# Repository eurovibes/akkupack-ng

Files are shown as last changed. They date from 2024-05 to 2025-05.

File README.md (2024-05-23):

<!-- SPDX-FileCopyrightText: 2024 Benedikt Spranger <b.spranger@linutronix.de> -->
<!-- SPDX-License-Identifier: CERN-OHL-S-2.0 -->


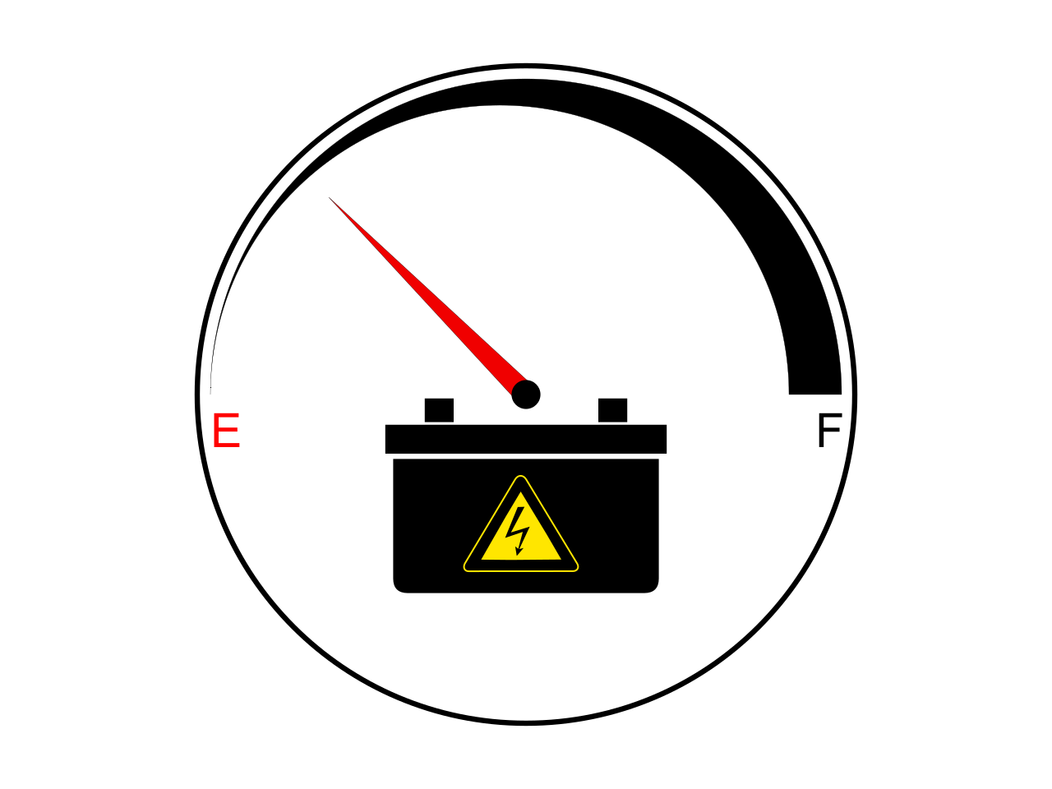
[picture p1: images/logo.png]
Akkupack-Ng logo


# Akkupack-NG - A AKKU-Pack gas gauge

## License rules

akkupack-ng is provided under the terms of the CERN-OHL-S license
version 2 as provided in the LICENSES/CERN-OHL-S-2.0 file.

Instead of adding license boilerplates to the individual files,
akkupack-ng uses SPDX license identifiers, which are machine parseable
and considered legaly equivalent.

The SPDX license identifier in akkupack-ng shall be added at the first
possible line in a file which can contain a comment. This is normally the
first line except for scripts. Scripts require the #!PATH_TO_INTERPRETER tag
in the first line; place the SPDX identifier into the second line.

The SPDX license identifier is added in form of a comment.

## Copyright and License

> Copyright Benedikt Spranger 2024.
> This source describes Open Hardware and is licensed under the CERNOHL-S v2.
> You may redistribute and modify this source and make products using it
> under the terms of the CERN-OHL-S v2 (https://ohwr.org/cern ohl s v2.txt ).
> This source is distributed WITHOUT ANY EXPRESS OR IMPLIED WARRANTY, INCLUDING
> OF MERCHANTABILITY, SATISFACTORY QUALITY AND FITNESS FOR A PARTICULAR PURPOSE.
> Please see the CERN-OHL-S v2 for applicable conditions.
> Source location: https://github.com/eurovibes/akkupack-ng
> As per CERN-OHL-S v2 section 4, should You produce hardware based
> on this source, You must where practicable maintain the Source Location
> visible on the external case of the akkupack-ng or other products you
> make using this source.

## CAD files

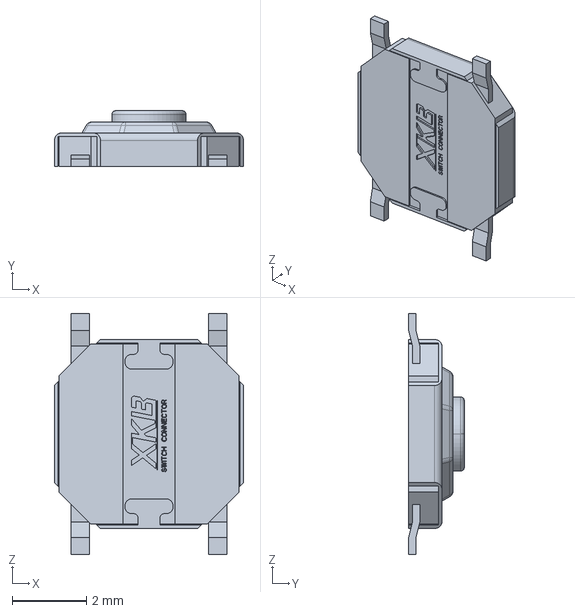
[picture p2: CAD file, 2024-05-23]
footprint/ts-1187a-b-a-b.stp
5.10 x 1.50 x 6.50 mm

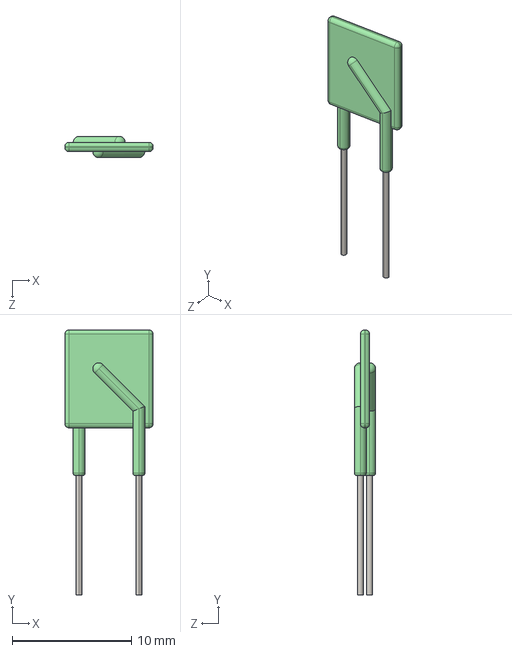
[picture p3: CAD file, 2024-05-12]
footprint/PTR016V-small.STEP
7.40 x 22.2 x 1.79 mm

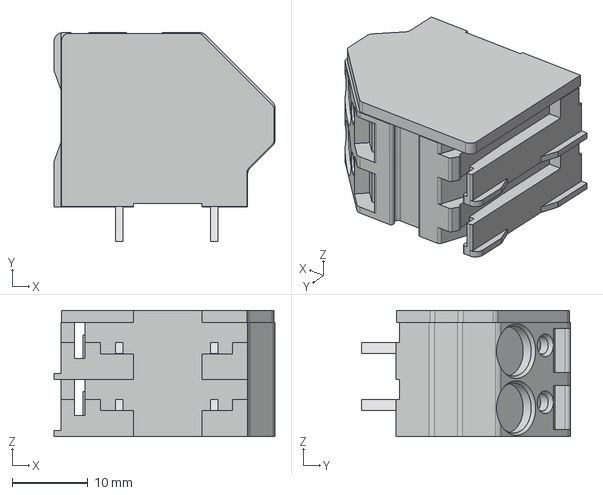
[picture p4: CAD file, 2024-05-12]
footprint/745-302.stp
29.1 x 27.5 x 16.6 mm

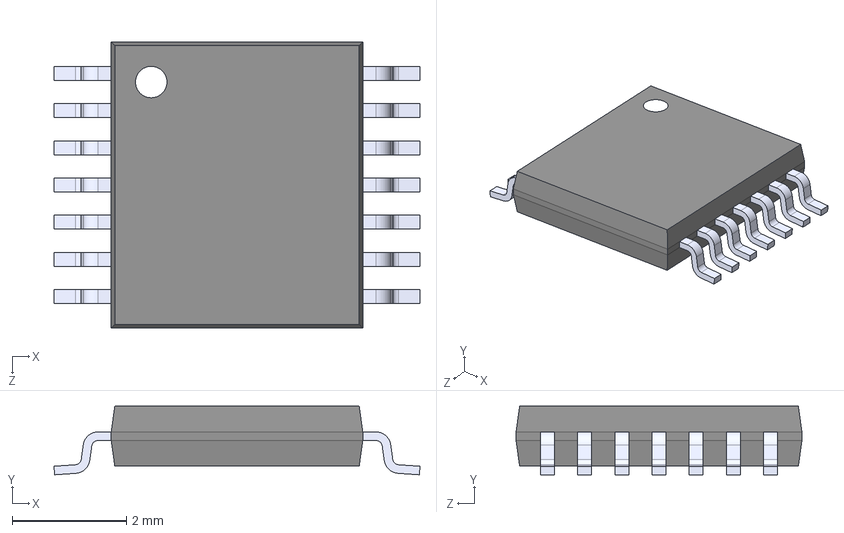
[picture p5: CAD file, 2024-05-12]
footprint/BQ34Z100PWR-G1.step
6.40 x 1.20 x 5.00 mm

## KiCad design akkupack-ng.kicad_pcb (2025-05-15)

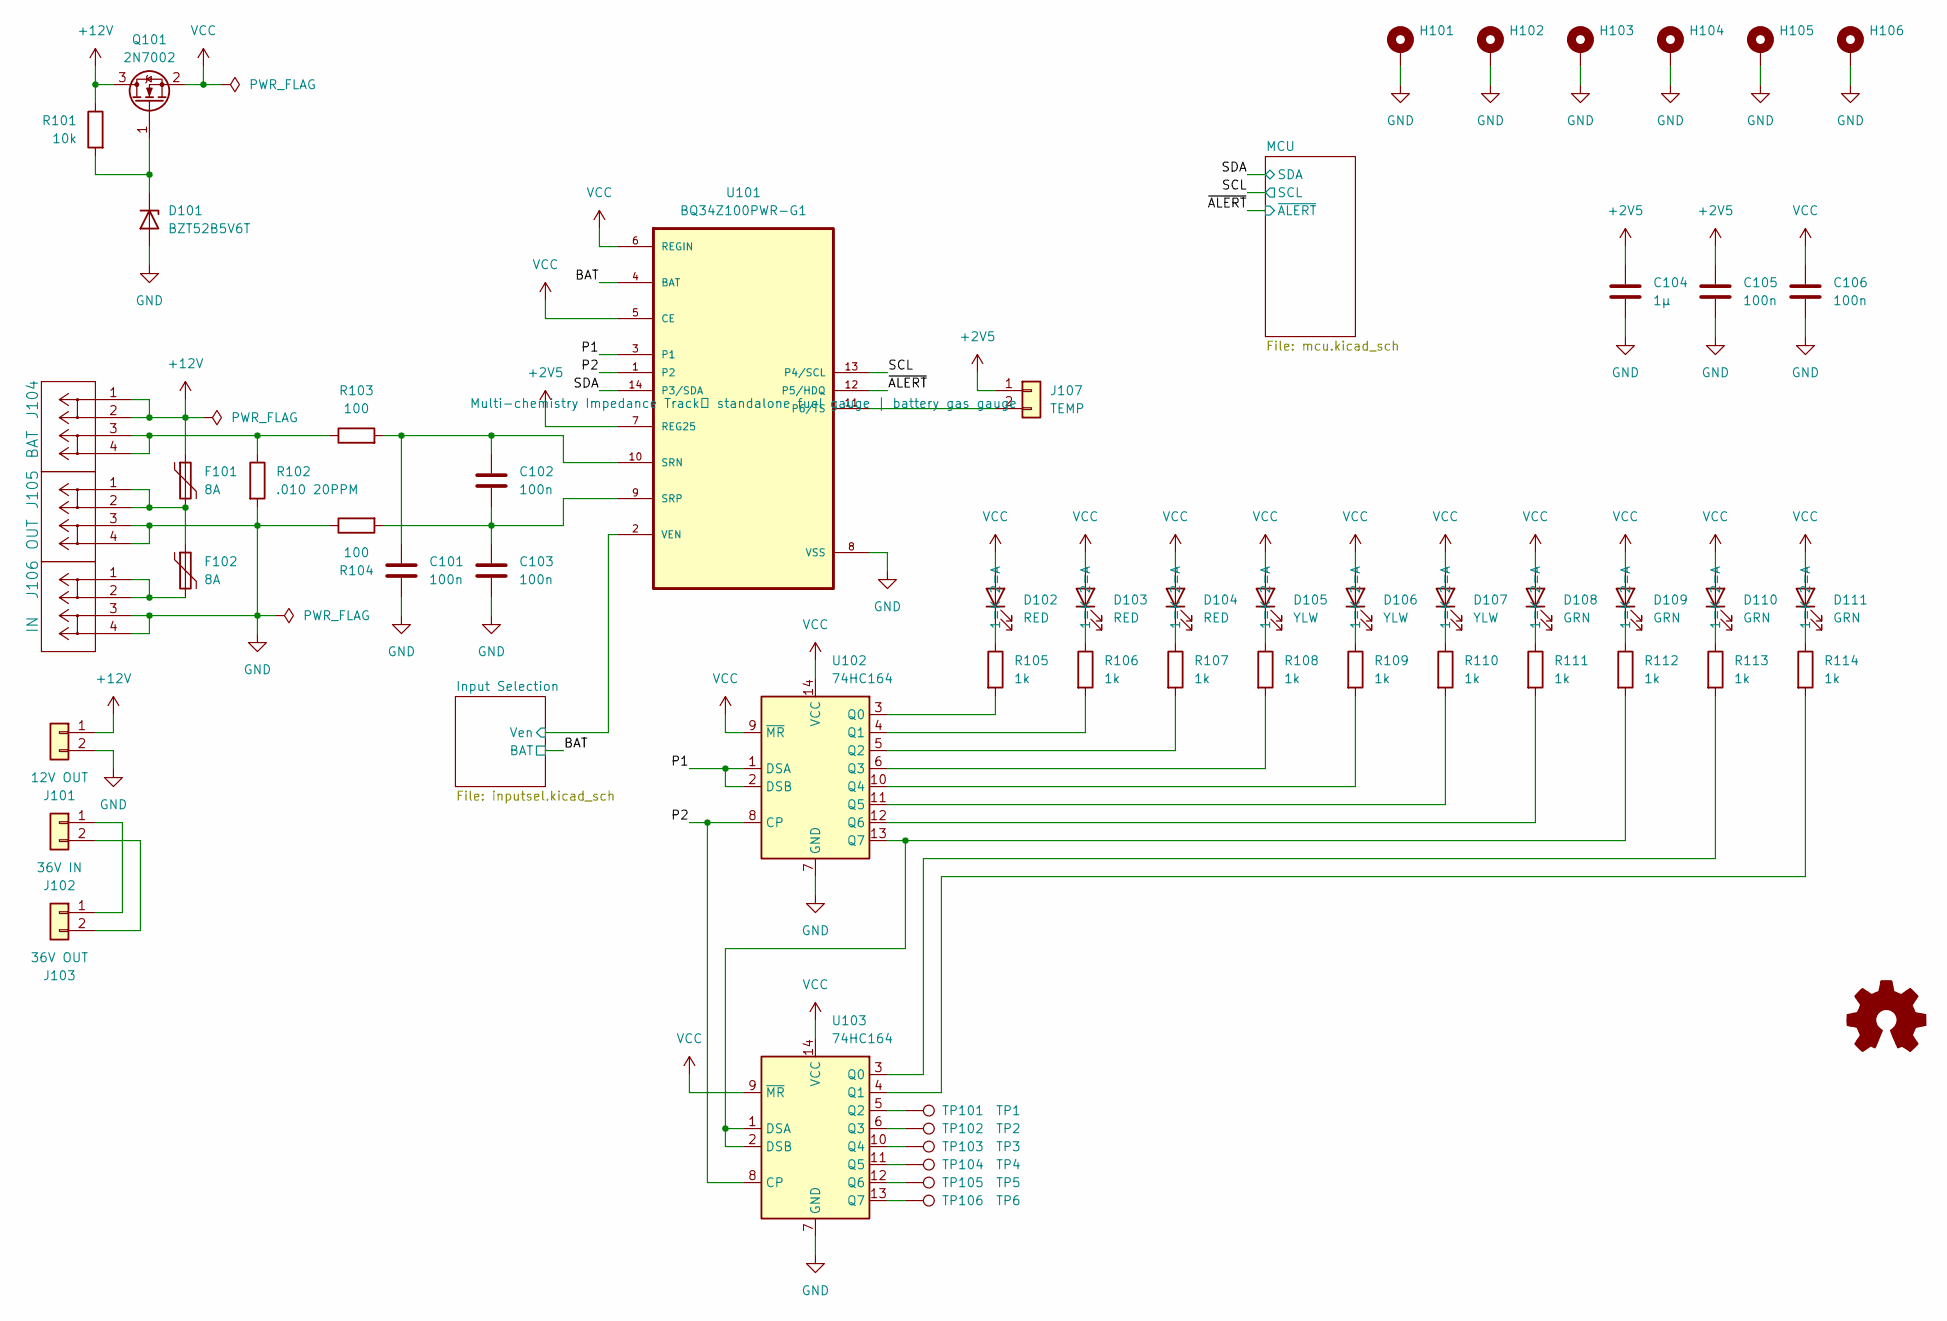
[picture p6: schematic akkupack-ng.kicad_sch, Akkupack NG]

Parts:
C101, C102, C103, C105, C106: 100n; C_0402_1005Metric; lcsc# C307331
C104: 1µ; C_0402_1005Metric; lcsc# C52923
D101: BZT52B5V6T; D_SOD-123F; lcsc# C2912016
D102, D103, D104: RED; LED_0603_1608Metric; lcsc# C7371906
D105, D106, D107: YLW; LED_0603_1608Metric; lcsc# C965803
D108, D109, D110, D111: GRN; LED_0603_1608Metric; lcsc# C965804
F101, F102: 8A; PTR016V0800; digikey# PTR016V0800-BK-ND
H101, H102, H103, H104, H105, H106: MountingHole_3.2mm_M3_Pad
J101: 12V OUT; TerminalBlock_WAGO_236-402_1x02_P5.00mm_45Degree; digikey# 2946-236-402-ND
J102: 36V IN; TerminalBlock_WAGO_236-402_1x02_P5.00mm_45Degree; digikey# 2946-236-402-ND
J103: 36V OUT; TerminalBlock_WAGO_236-402_1x02_P5.00mm_45Degree; digikey# 2946-236-402-ND
J104: BAT; 745-302_WAGO; digikey# 2946-745-302-ND
J105: OUT; 745-302_WAGO; digikey# 2946-745-302-ND
J106: IN; 745-302_WAGO; digikey# 2946-745-302-ND
J107: TEMP; TerminalBlock_WAGO_236-402_1x02_P5.00mm_45Degree; digikey# 2946-236-402-ND
Q101: 2N7002; SOT-23; lcsc# C8545
R101: 10k; R_0402_1005Metric; lcsc# C25744
R102: .010 20PPM; R_2512_6332Metric; lcsc# C466594
R103, R104: 100; R_0402_1005Metric; lcsc# C25076
R105, R106, R107, R108, R109, R110, R111, R112, R113, R114: 1k; R_0402_1005Metric; lcsc# C11702
TP101: TP1; TestPoint_Pad_D1.0mm
TP102: TP2; TestPoint_Pad_D1.0mm
TP103: TP3; TestPoint_Pad_D1.0mm
TP104: TP4; TestPoint_Pad_D1.0mm
TP105: TP5; TestPoint_Pad_D1.0mm
TP106: TP6; TestPoint_Pad_D1.0mm
U101: BQ34Z100PWR-G1; SOP65P640X120-14N; lcsc# C91302
U102, U103: 74HC164; TSSOP-14_4.4x5mm_P0.65mm; lcsc# C406867

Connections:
+2V5: C104.1, C105.1, J107.1, U101.7 (REG25); also elsewhere on the board
+12V: F101.1, J101.1, J104.1, J104.2, Q101.3 (D), R101.1; also elsewhere on the board
/BAT: U101.4 (BAT); also elsewhere on the board
/Input Selection/Ven: U101.2 (VEN); also elsewhere on the board
/P1: U101.3 (P1), U102.1 (DSA), U102.2 (DSB)
/P2: U101.1 (P2), U102.8 (CP), U103.8 (CP)
/SCL: U101.13 (P4/SCL); also elsewhere on the board
/SDA: U101.14 (P3/SDA); also elsewhere on the board
/~ALERT: U101.12 (P5/HDQ); also elsewhere on the board
GND: C101.2, C103.2, C104.2, C105.2, C106.2, D101.2 (A), H101.1, H102.1, H103.1, H104.1, H105.1, H106.1, J101.2, J105.3, J105.4, J106.3, J106.4, R102.2, R104.1, U101.8 (VSS), U102.7 (GND), U103.7 (GND); also elsewhere on the board
unnamed: D101.1 (K), Q101.1 (G), R101.2
unnamed: D102.1 (K), R105.1
unnamed: D103.1 (K), R106.1
unnamed: D104.1 (K), R107.1
unnamed: D105.1 (K), R108.1
unnamed: D106.1 (K), R109.1
unnamed: D107.1 (K), R110.1
unnamed: D108.1 (K), R111.1
unnamed: D109.1 (K), R112.1
unnamed: D110.1 (K), R113.1
unnamed: D111.1 (K), R114.1
unnamed: F101.2, F102.1, J105.1, J105.2
unnamed: F102.2, J106.1, J106.2
unnamed: J102.1, J103.1
unnamed: J102.2, J103.2
unnamed: J104.3, J104.4, R102.1, R103.1
unnamed: J107.2, U101.11 (P6/TS)
unnamed: C101.1, C102.1, R103.2, U101.10 (SRN)
unnamed: C102.2, C103.1, R104.2, U101.9 (SRP)
unnamed: R105.2, U102.3 (Q0)
unnamed: R106.2, U102.4 (Q1)
unnamed: R107.2, U102.5 (Q2)
unnamed: R108.2, U102.6 (Q3)
unnamed: R109.2, U102.10 (Q4)
unnamed: R110.2, U102.11 (Q5)
unnamed: R111.2, U102.12 (Q6)
unnamed: R112.2, U102.13 (Q7), U103.1 (DSA), U103.2 (DSB)
unnamed: R113.2, U103.3 (Q0)
unnamed: R114.2, U103.4 (Q1)
unnamed: TP101.1, U103.5 (Q2)
unnamed: TP102.1, U103.6 (Q3)
unnamed: TP103.1, U103.10 (Q4)
unnamed: TP104.1, U103.11 (Q5)
unnamed: TP105.1, U103.12 (Q6)
unnamed: TP106.1, U103.13 (Q7)
VCC: C106.1, D102.2 (A), D103.2 (A), D104.2 (A), D105.2 (A), D106.2 (A), D107.2 (A), D108.2 (A), D109.2 (A), D110.2 (A), D111.2 (A), Q101.2 (S), U101.5 (CE), U101.6 (REGIN), U102.9 (~MR), U102.14 (VCC), U103.9 (~MR), U103.14 (VCC)

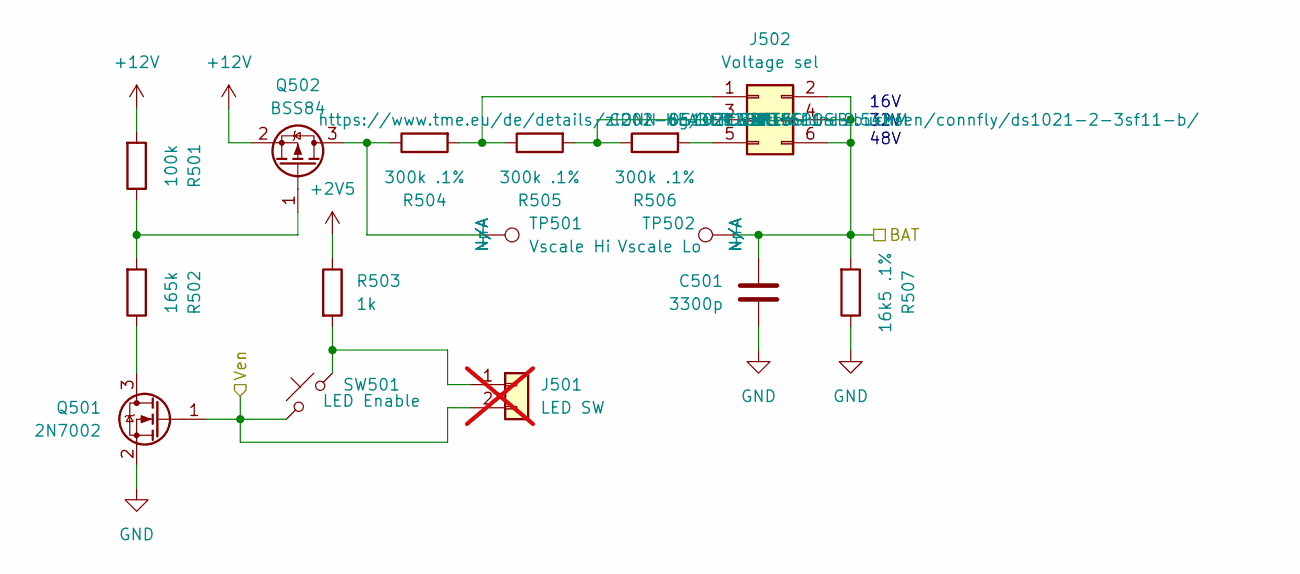
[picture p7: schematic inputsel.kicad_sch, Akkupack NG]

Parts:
C501: 3300p; C_1206_3216Metric; lcsc# C76663
J501: LED SW; JST_XH_B2B-XH-A_1x02_P2.50mm_Vertical; digikey# 455-B2B-XH-A-ND; not fitted
J502: Voltage sel; PinHeader_2x03_P2.54mm_Vertical
Q501: 2N7002; SOT-23; lcsc# C8545
Q502: BSS84; SOT-23; lcsc# C427395
R501: 100k; R_0402_1005Metric; lcsc# C25741
R502: 165k; R_0402_1005Metric; lcsc# C321332
R503: 1k; R_0402_1005Metric; lcsc# C11702
R504, R505, R506: 300k .1%; R_0603_1608Metric; lcsc# C335091
R507: 16k5 .1%; R_0603_1608Metric; lcsc# C861693
SW501: LED Enable; Push_SW_5x5; lcsc# C318884
TP501: Vscale Hi; TestPoint_Pad_1.5x1.5mm
TP502: Vscale Lo; TestPoint_Pad_1.5x1.5mm

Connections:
+2V5: R503.1; also elsewhere on the board
+12V: Q502.2 (S), R501.2; also elsewhere on the board
/BAT: C501.1, J502.2, J502.4, J502.6, R507.2, TP502.1; also elsewhere on the board
/Input Selection/Ven: J501.2, Q501.1 (G), SW501.1; also elsewhere on the board
GND: C501.2, Q501.2 (S), R507.1; also elsewhere on the board
unnamed: J501.1, R503.2, SW501.2
unnamed: J502.1, R504.2, R505.1
unnamed: J502.3, R505.2, R506.1
unnamed: J502.5, R506.2
unnamed: Q501.3 (D), R502.1
unnamed: Q502.3 (D), R504.1, TP501.1
unnamed: Q502.1 (G), R501.1, R502.2

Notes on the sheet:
16V 32V 48V

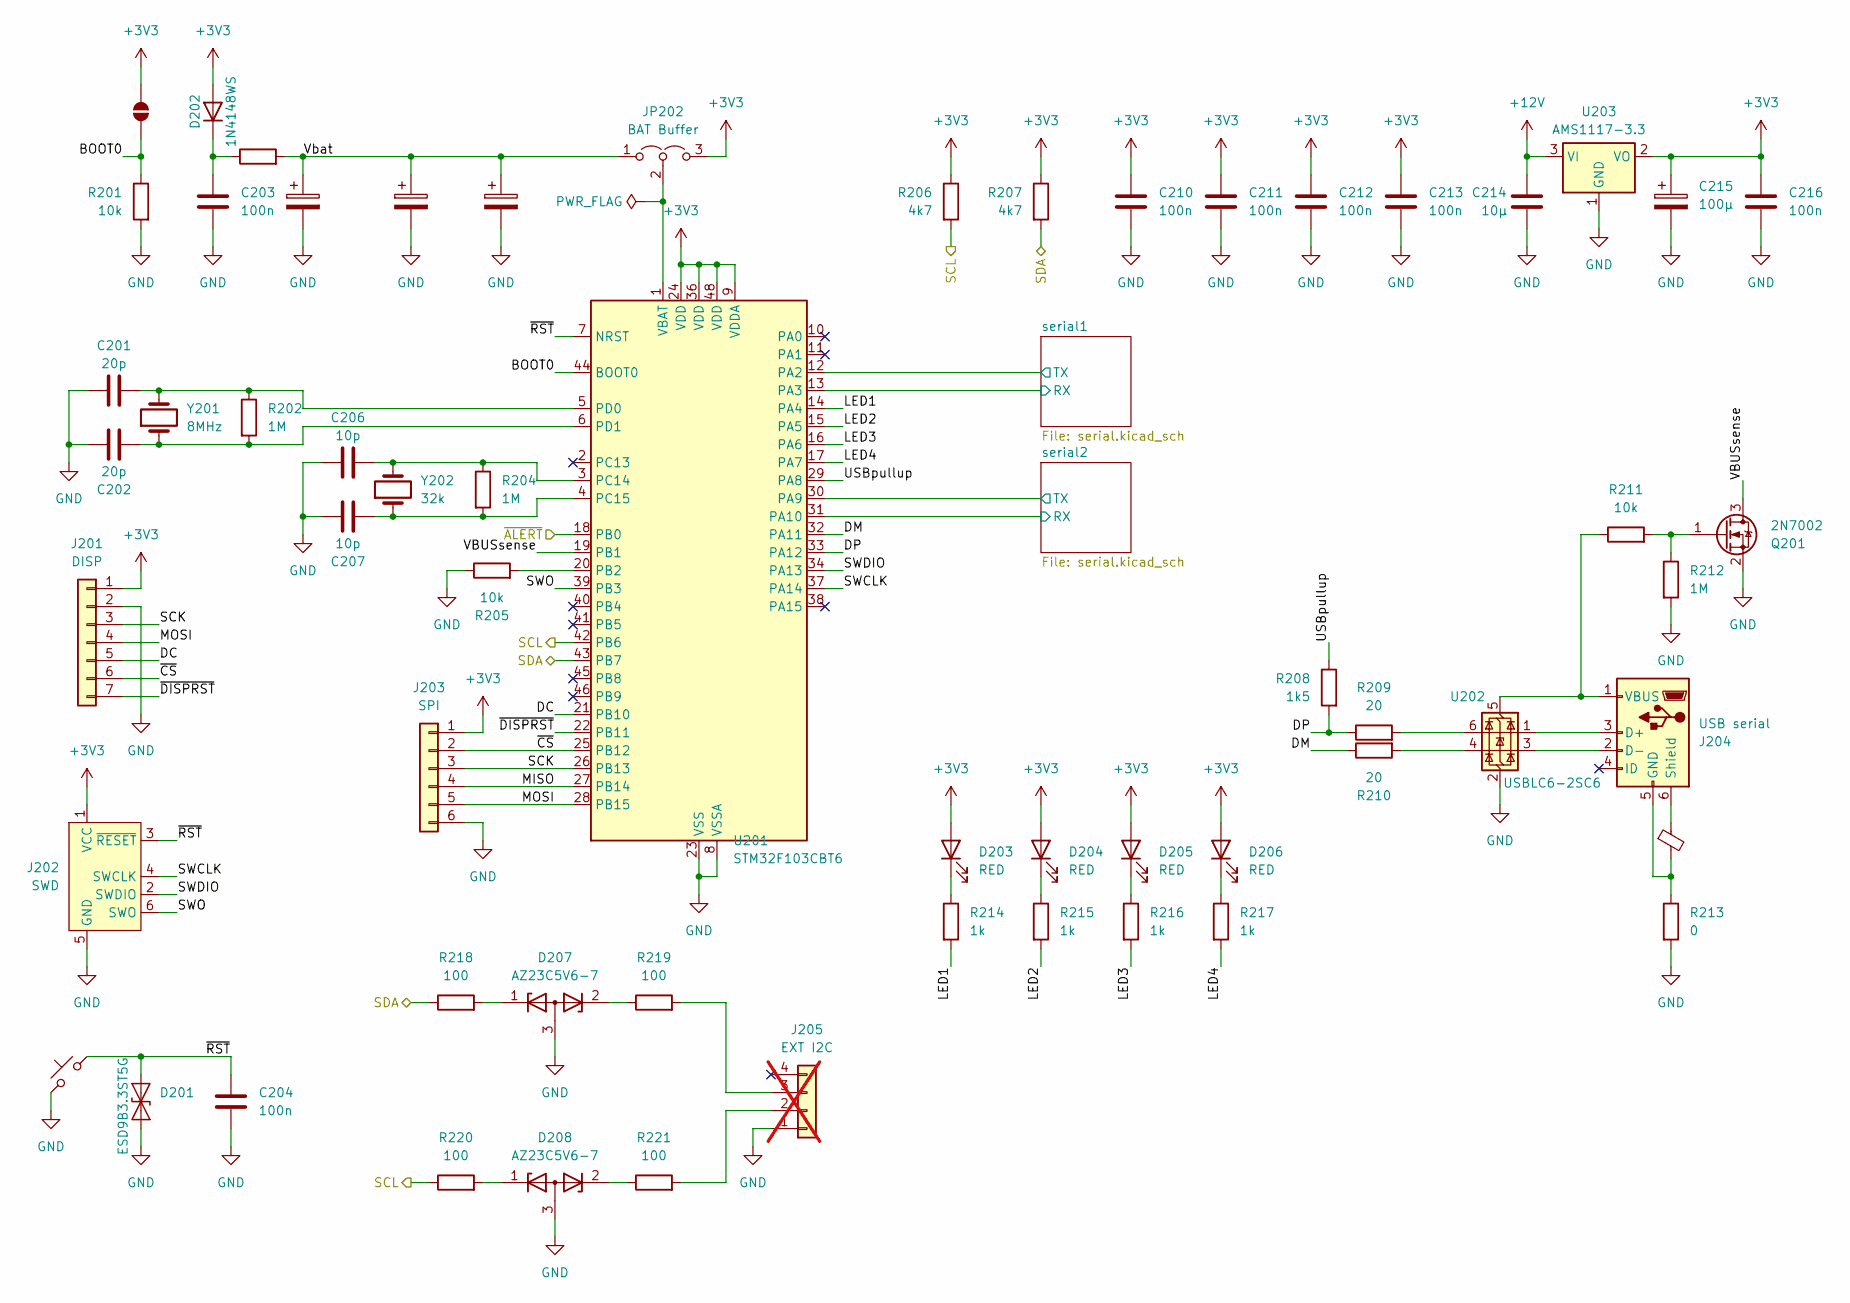
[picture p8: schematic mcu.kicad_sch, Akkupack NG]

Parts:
C201, C202: 20p; C_0402_1005Metric; lcsc# C1554
C203, C204, C210, C211, C212, C213, C216: 100n; C_0402_1005Metric; lcsc# C307331
C205, C208, C209: 1F; CP_Radial_D8.0mm_P3.50mm
C206, C207: 10p; C_0402_1005Metric; lcsc# C32949
C214: 10µ; C_0603_1608Metric; lcsc# C96446
C215: 100µ; CP_EIA-3528-21_Kemet-B; lcsc# C16133
D201: ESD9B3.3ST5G; D_SOD-923; lcsc# C96512
D202: 1N4148WS; D_SOD-323; lcsc# C2128
D203, D204, D205, D206: RED; LED_0603_1608Metric; lcsc# C7371906
D207, D208: AZ23C5V6-7; SOT-23; lcsc# C98737
FB201: FerriteBead_Small; L_0805_2012Metric; lcsc# C1015
J201: DISP; PinSocket_1x07_P2.54mm_Vertical; digikey# 609-6552-ND
J202: SWD; Tag-Connect_TC2030-IDC-FP_2x03_P1.27mm_Vertical
J203: SPI; PinSocket_1x06_P2.54mm_Vertical; digikey# 952-1809-ND
J204: USB serial; USB_Micro-AB_Molex_47590-0001; lcsc# C136001
J205: EXT I2C; Molex_KK-254_AE-6410-04A_1x04_P2.54mm_Vertical; digikey# WM4113-ND; not fitted
JP201: BOOT0; SolderJumper-2_P1.3mm_Open_Pad1.0x1.5mm
JP202: BAT Buffer; PinHeader_1x03_P2.54mm_Vertical
Q201: 2N7002; SOT-23; lcsc# C8545
R201, R205, R211: 10k; R_0402_1005Metric; lcsc# C25744
R202, R204, R212: 1M; R_0402_1005Metric; lcsc# C25900
R203: 22; R_1206_3216Metric; lcsc# C17958
R206, R207: 4k7; R_0402_1005Metric; lcsc# C25900
R208: 1k5; R_0402_1005Metric; lcsc# C25867
R209, R210: 20; R_0603_1608Metric; lcsc# C22950
R213: 0; R_0402_1005Metric; lcsc# C17168
R214, R215, R216, R217: 1k; R_0402_1005Metric; lcsc# C11702
R218, R219, R220, R221: 100; R_0402_1005Metric; lcsc# C25076
SW201: Reset; Push_SW_5x5; lcsc# C318884
U201: STM32F103CBT6; LQFP-48_7x7mm_P0.5mm; lcsc# C8304
U202: USBLC6-2SC6; SOT-23-6; lcsc# C2827654
U203: AMS1117-3.3; SOT-223-3_TabPin2; lcsc# C6186
Y201: 8MHz; Crystal_SMD_5032-2Pin_5.0x3.2mm; lcsc# C115962
Y202: 32k; Crystal_SMD_3215-2Pin_3.2x1.5mm; lcsc# C32346

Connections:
+3V3: C210.1, C211.1, C212.1, C213.1, C215.1, C216.1, D202.2 (A), D203.2 (A), D204.2 (A), D205.2 (A), D206.2 (A), J201.1, J202.1 (VCC), J203.1, JP201.2 (B), JP202.3 (B), R206.1, R207.1, U201.9 (VDDA), U201.24 (VDD), U201.36 (VDD), U201.48 (VDD), U203.2 (VO)
+12V: C214.1, U203.3 (VI); also elsewhere on the board
/MCU/BOOT0: JP201.1 (A), R201.1, U201.44 (BOOT0)
/MCU/DC: J201.5, U201.21 (PB10)
/MCU/DM: R210.1, U201.32 (PA11)
/MCU/DP: R208.2, R209.1, U201.33 (PA12)
/MCU/LED1: R214.2, U201.14 (PA4)
/MCU/LED2: R215.2, U201.15 (PA5)
/MCU/LED3: R216.2, U201.16 (PA6)
/MCU/LED4: R217.2, U201.17 (PA7)
/MCU/MISO: J203.4, U201.27 (PB14)
/MCU/MOSI: J201.4, J203.5, U201.28 (PB15)
/MCU/SCK: J201.3, J203.3, U201.26 (PB13)
/MCU/SWCLK: J202.4 (SWCLK), U201.37 (PA14)
/MCU/SWDIO: J202.2 (SWDIO), U201.34 (PA13)
/MCU/SWO: J202.6 (SWO), U201.39 (PB3)
/MCU/USBpullup: R208.1, U201.29 (PA8)
/MCU/VBUSsense: Q201.3 (D), U201.19 (PB1)
/MCU/Vbat: C205.1, C208.1, C209.1, JP202.1 (A), R203.2
/MCU/serial1/RX: U201.13 (PA3); also elsewhere on the board
/MCU/serial1/TX: U201.12 (PA2); also elsewhere on the board
/MCU/serial2/RX: U201.31 (PA10); also elsewhere on the board
/MCU/serial2/TX: U201.30 (PA9); also elsewhere on the board
/MCU/~CS: J201.6, J203.2, U201.25 (PB12)
/MCU/~DISPRST: J201.7, U201.22 (PB11)
/MCU/~RST: C204.1, D201.2 (A2), J202.3 (~RESET), SW201.1, U201.7 (NRST)
/SCL: R206.2, R220.1, U201.42 (PB6); also elsewhere on the board
/SDA: R207.2, R218.1, U201.43 (PB7); also elsewhere on the board
/~ALERT: U201.18 (PB0); also elsewhere on the board
GND: C201.1, C202.1, C203.2, C204.2, C205.2, C206.1, C207.1, C208.2, C209.2, C210.2, C211.2, C212.2, C213.2, C214.2, C215.2, C216.2, D201.1 (A1), D207.3 (A), D208.3 (A), J201.2, J202.5 (GND), J203.6, J205.1, Q201.2 (S), R201.2, R205.1, R212.2, R213.2, SW201.2, U201.8 (VSSA), U201.23 (VSS), U201.35 (VSS), U201.47 (VSS), U202.2 (GND), U203.1 (GND); also elsewhere on the board
unnamed: C203.1, D202.1 (K), R203.1
unnamed: D203.1 (K), R214.1
unnamed: D204.1 (K), R215.1
unnamed: D205.1 (K), R216.1
unnamed: D206.1 (K), R217.1
unnamed: D207.1 (K), R218.2
unnamed: D207.2 (K), R219.1
unnamed: D208.1 (K), R220.2
unnamed: D208.2 (K), R221.1
unnamed: J204.3 (D+), U202.1 (I/O1)
unnamed: J204.2 (D-), U202.3 (I/O2)
unnamed: FB201.2, J204.5 (GND), R213.1
unnamed: FB201.1, J204.6 (Shield)
unnamed: J204.1 (VBUS), R211.1, U202.5 (VBUS)
unnamed: J205.2, R221.2
unnamed: J205.3, R219.2
unnamed: JP202.2 (C), U201.1 (VBAT)
unnamed: Q201.1 (G), R211.2, R212.1
unnamed: R209.2, U202.6 (I/O1)
unnamed: R210.2, U202.4 (I/O2)
unnamed: R205.2, U201.20 (PB2)
unnamed: C206.2, R204.1, U201.3 (PC14), Y202.2
unnamed: C207.2, R204.2, U201.4 (PC15), Y202.1
unnamed: C201.2, R202.1, U201.5 (PD0), Y201.2
unnamed: C202.2, R202.2, U201.6 (PD1), Y201.1

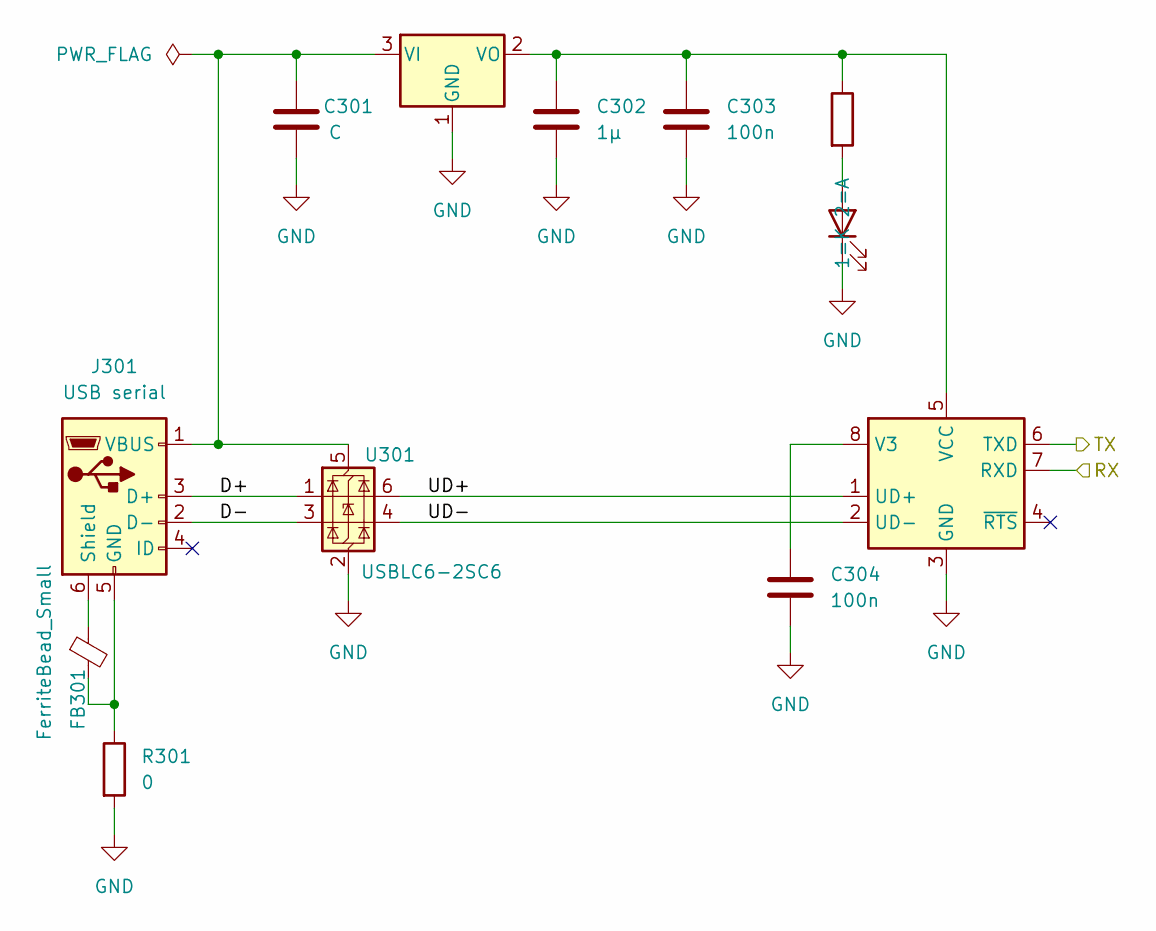
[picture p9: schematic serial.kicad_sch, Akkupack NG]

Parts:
C301: C; C_0805_2012Metric; lcsc# C28323
C302: 1µ; C_0402_1005Metric; lcsc# C52923
C303, C304: 100n; C_0402_1005Metric; lcsc# C307331
D301: LED; LED_0603_1608Metric; lcsc# C7371906
FB301: FerriteBead_Small; L_0805_2012Metric; lcsc# C1015
J301: USB serial; USB_Micro-AB_Molex_47590-0001; lcsc# C136001
R301: 0; R_0402_1005Metric; lcsc# C17168
R302: 1k; R_0402_1005Metric; lcsc# C11702
U301: USBLC6-2SC6; SOT-23-6; lcsc# C2827654
U302: XC6206PxxxMR; SOT-23-3; lcsc# C5446
U303: CH330N; SOIC-8_3.9x4.9mm_P1.27mm; lcsc# C2977777

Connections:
/MCU/serial1/D+: J301.3 (D+), U301.1 (I/O1)
/MCU/serial1/D-: J301.2 (D-), U301.3 (I/O2)
/MCU/serial1/RX: U303.7 (RXD); also elsewhere on the board
/MCU/serial1/TX: U303.6 (TXD); also elsewhere on the board
/MCU/serial1/UD+: U301.6 (I/O1), U303.1 (UD+)
/MCU/serial1/UD-: U301.4 (I/O2), U303.2 (UD-)
GND: C301.2, C302.2, C303.2, C304.2, D301.1 (K), R301.2, U301.2 (GND), U302.1 (GND), U303.3 (GND); also elsewhere on the board
unnamed: D301.2 (A), R302.2
unnamed: FB301.2, J301.5 (GND), R301.1
unnamed: FB301.1, J301.6 (Shield)
unnamed: C301.1, J301.1 (VBUS), U301.5 (VBUS), U302.3 (VI)
unnamed: C302.1, C303.1, R302.1, U302.2 (VO), U303.5 (VCC)
unnamed: C304.1, U303.8 (V3)

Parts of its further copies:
C401: C; C_0805_2012Metric; lcsc# C28323
C402: 1µ; C_0402_1005Metric; lcsc# C52923
C403, C404: 100n; C_0402_1005Metric; lcsc# C307331
D401: LED; LED_0603_1608Metric; lcsc# C7371906
FB401: FerriteBead_Small; L_0805_2012Metric; lcsc# C1015
J401: USB serial; USB_Micro-AB_Molex_47590-0001; lcsc# C136001
R401: 0; R_0402_1005Metric; lcsc# C17168
R402: 1k; R_0402_1005Metric; lcsc# C11702
U401: USBLC6-2SC6; SOT-23-6; lcsc# C2827654
U402: XC6206PxxxMR; SOT-23-3; lcsc# C5446
U403: CH330N; SOIC-8_3.9x4.9mm_P1.27mm; lcsc# C2977777

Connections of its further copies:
/MCU/serial2/D+: J401.3 (D+), U401.1 (I/O1)
/MCU/serial2/D-: J401.2 (D-), U401.3 (I/O2)
/MCU/serial2/RX: U403.7 (RXD); also elsewhere on the board
/MCU/serial2/TX: U403.6 (TXD); also elsewhere on the board
/MCU/serial2/UD+: U401.6 (I/O1), U403.1 (UD+)
/MCU/serial2/UD-: U401.4 (I/O2), U403.2 (UD-)
GND: C401.2, C402.2, C403.2, C404.2, D401.1 (K), R401.2, U401.2 (GND), U402.1 (GND), U403.3 (GND); also elsewhere on the board
unnamed: D401.2 (A), R402.2
unnamed: FB401.2, J401.5 (GND), R401.1
unnamed: FB401.1, J401.6 (Shield)
unnamed: C401.1, J401.1 (VBUS), U401.5 (VBUS), U402.3 (VI)
unnamed: C402.1, C403.1, R402.1, U402.2 (VO), U403.5 (VCC)
unnamed: C404.1, U403.8 (V3)

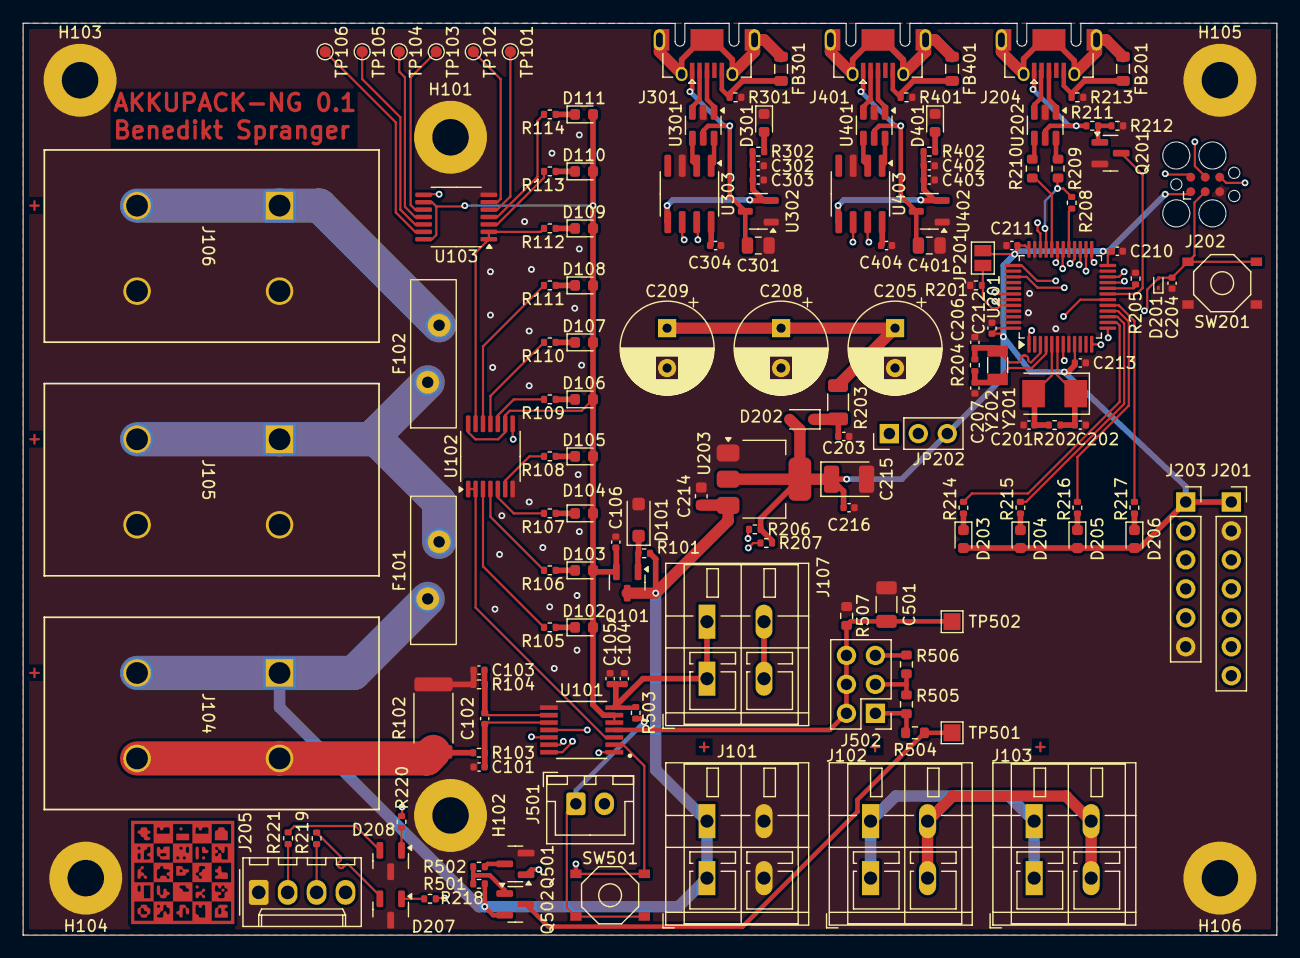
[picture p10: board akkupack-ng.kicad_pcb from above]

Board: 4 copper layers, 110.0 x 80.0 mm, 155 parts (0 on the bottom side), 123 nets.

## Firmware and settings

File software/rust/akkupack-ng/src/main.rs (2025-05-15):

// SPDX-License-Identifier: Apache-2.0
//
// SPDX-FileCopyrightText: 2025 Benedikt Spranger <b.spranger@linutronix.de>

#![no_std]
#![no_main]

use defmt::*;
use embassy_executor::Spawner;
use embassy_stm32::Config;
use {defmt_rtt as _, panic_probe as _};

use akkupack_ng::{BqXxx, Gauge, SubCmds};

const ADDRESS: u8 = 0x55;

#[embassy_executor::main]
async fn main(_spawner: Spawner) {
    info!("Hello BQ34Z100-G1!");
    let config = Config::default();
    let p = embassy_stm32::init(config);

    let mut bq = BqXxx::new(p, ADDRESS);

    info!("Device type    : {}", bq.dev_type());

    info!("MaxError       : {} %", bq.get_max_error());
    info!("State of charge: {} %", bq.get_state_of_charge());
    info!("Device type    : {}", bq.cntrl(SubCmds::SUB_CMD_DEVICE_TYPE));
    info!("FW version     : {:#06x}", bq.cntrl(SubCmds::SUB_CMD_FW_VERSION));
    info!("HW version     : {}", bq.cntrl(SubCmds::SUB_CMD_HW_VERSION));
    info!("DF version     : {}", bq.cntrl(SubCmds::SUB_CMD_DF_VERSION));
    info!("Voltage        : {} V", bq.get_voltage());
    info!("Full capacity  : {}", bq.get_cap_full());
    info!("Rem. capacity  : {}", bq.get_cap_remain());
    info!("Current        : {}", bq.get_current());
    info!("Current Avg    : {}", bq.get_current_avg());
    info!("Flags          : {:#010x}", bq.get_flags());
    info!("Temperature    : {}", bq.get_temp());
    info!("Control status : {:#06x}", bq.cntrl(SubCmds::SUB_CMD_CONTROL_STATUS));

    // gauge_execute_fs(pHandle, pFileBuffer)

    //read data class DC_STATE:
    // n = gauge_read_data_class(pHandle, DC_STATE, pData, DC_STATE_LENGTH);
    // if (n) printf("Error reading data class, %d\n\r", n);
    // printf("Data Class 'State' (0x52):\n\r");
    // print_data(pData, DC_STATE_LENGTH);
    // this was for bq2742x - change offsets for your gauge
    // pData[10] = (DESIGN_CAPACITY & 0xFF00) >> 8;
    // pData[11] = DESIGN_CAPACITY & 0xFF;
    // pData[12] = (DESIGN_ENERGY & 0xFF00) >> 8;
    // pData[13] = DESIGN_ENERGY & 0xFF;
    // pData[16] = (TERMINATE_VOLTAGE & 0xFF00) >>8;
    // pData[17] = TERMINATE_VOLTAGE & 0xFF;
    // pData[27] = (TAPER_RATE & 0xFF00) >> 8;
    // pData[28] = TAPER_RATE & 0xFF;
    //write data class DC_STATE:
    // gauge_cfg_update(pHandle);
    // n = gauge_write_data_class(pHandle, DC_STATE, pData, DC_STATE_LENGTH);
    // if (n) printf("Error writing data class, %d\n\r", n);
    // gauge_exit(pHandle, SOFT_RESET);

}

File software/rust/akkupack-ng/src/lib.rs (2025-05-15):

// SPDX-License-Identifier: Apache-2.0
//
// SPDX-FileCopyrightText: 2025 Benedikt Spranger <b.spranger@linutronix.de>

#![no_std]

use defmt::*;
use embassy_stm32::i2c::{Error, I2c};
use embassy_stm32::mode::Blocking;
use embassy_stm32::time::Hertz;
use embassy_stm32::Peripherals;
use {defmt_rtt as _, panic_probe as _};

macro_rules! def_enum {
    (
        $(#[$attr:meta])*
        $vis:vis $name:ident => $ty:ty {
            $($variant:ident => $val:expr),+
            $(,)?
        }
    ) => {
        $(#[$attr])*
        $vis struct $name($ty);

        impl $name {
            $(
                pub const $variant: Self = Self($val);
            )+

            pub const VARIANTS: &'static [Self] = &[$(Self::$variant),+];

            pub const fn get(self) -> $ty {
                self.0
            }
        }
    };
}

def_enum!(
    #[derive(PartialEq,Eq, Debug)]
    pub Cmd => u8 {
        CMD_AI => 0x0a,
        CMD_CNTL => 0x00,
        CMD_FCC => 0x06,
        CMD_FLAGS => 0x0e,
        CMD_FLAGSB => 0x12,
        CMD_I => 0x10,
        CMD_ME => 0x03,
        CMD_RM => 0x04,
        CMD_SOC => 0x02,
        CMD_TEMP => 0x0c,
        CMD_VOLT => 0x04,
        CMD_ATTE => 0x18,
        CMD_ATTF => 0x1A,
        CMD_PCHG => 0x1C,
        CMD_DOD0T => 0x1E,
        CMD_AE => 0x24,
        CMD_AP => 0x26,
        CMD_SERNUM => 0x28,
        CMD_INTTEMP => 0x2A,
        CMD_CC => 0x2C,
        CMD_SOH => 0x2E,
        CMD_CHGV => 0x30,
        CMD_CHGI => 0x32,
        CMD_PKCFG => 0x3A,
        CMD_DCAP => 0x3C,
        CMD_DFCLS => 0x3E,
        CMD_DFBLK => 0x3F,
        CMD_A_DF => 0x40,
        CMD_ACKS_DFD => 0x54,
        CMD_DFD => 0x55,
        CMD_DFDCKS => 0x60,
        CMD_DFDCNTL => 0x61,
        CMD_GN => 0x62,
        CMD_LS => 0x63,
        CMD_DEOC => 0x64,
        CMD_QS => 0x66,
        CMD_TRC => 0x68,
        CMD_TFCC => 0x6A,
        CMD_ST => 0x6C,
        CMD_QPC => 0x6E,
        CMD_DOD0 => 0x70,
        CMD_QD0 => 0x72,
        CMD_QT => 0x74,
    }
);

/*
Gauge control subcommands:
Control function   Subcmd Sealed access Description 
CONTROL_STATUS     0x0000 Yes Reports the status of key features.
DEVICE_TYPE        0x0001 Yes Reports the device type of 0x100 (indicating BQ34Z100-G1)
FW_VERSION         0x0002 Yes Reports the firmware version on the device type
HW_VERSION         0x0003 Yes Reports the hardware version of the device type
RESET_DATA         0x0005 Yes Returns reset data
PREV_MACWRITE      0x0007 Yes Returns previous Control() command code
CHEM_ID            0x0008 Yes Reports the chemical identifier of the Impedance Track configuration
BOARD_OFFSET       0x0009 Yes Forces the device to measure and store the board offset
CC_OFFSET          0x000A Yes Forces the device to measure the internal CC offset
CC_OFFSET_SAVE     0x000B Yes Forces the device to store the internal CC offset
DF_VERSION         0x000C Yes Reports the data flash version on the device
SET_FULLSLEEP      0x0010 Yes Set the [FULLSLEEP] bit in the control register to 1
STATIC_CHEM_CHKSUM 0x0017 Yes Calculates chemistry checksum
SEALED             0x0020 No  Places the device in SEALED access mode
IT_ENABLE          0x0021 No  Enables the Impedance Track algorithm
CAL_ENABLE         0x002D No  Toggle CALIBRATION mode enable
RESET              0x0041 No  Forces a full reset of the BQ34Z100-G1
EXIT_CAL           0x0080 No  Exit CALIBRATION mode
ENTER_CAL          0x0081 No  Enter CALIBRATION mode
OFFSET_CAL         0x0082 No  Reports internal CC offset in CALIBRATION mod
*/

def_enum!(
    #[derive(PartialEq,Eq, Debug)]
    pub SubCmds => u16 {
        SUB_CMD_CONTROL_STATUS => 0x0000,
        SUB_CMD_DEVICE_TYPE => 0x0001,
        SUB_CMD_FW_VERSION => 0x0002,
        SUB_CMD_HW_VERSION => 0x0003,
        SUB_CMD_RESET_DATA => 0x0005,
        SUB_CMD_PREV_MACWRITE => 0x0007,
        SUB_CMD_CHEM_ID => 0x0008,
        SUB_CMD_BOARD_OFFSET => 0x0009,
        SUB_CMD_CC_OFFSET => 0x000A,
        SUB_CMD_CC_OFFSET_SAVE => 0x000B,
        SUB_CMD_DF_VERSION => 0x000C,
        SUB_CMD_SET_FULLSLEEP => 0x0010,
        SUB_CMD_STATIC_CHEM_CHKSUM => 0x0017,
        SUB_CMD_SEALED => 0x0020,
        SUB_CMD_IT_ENABLE => 0x0021,
        SUB_CMD_CAL_ENABLE => 0x002D,
        SUB_CMD_RESET => 0x0041,
        SUB_CMD_EXIT_CAL => 0x0080,
        SUB_CMD_ENTER_CAL => 0x0081,
        SUB_CMD_OFFSET_CAL => 0x0082,
    }
);

pub trait Gauge {
    fn cntrl(&mut self, subcmd: SubCmds) -> Result<u16, Error>;
    fn get_cap_full(&mut self) -> Result<u16, Error>;
    fn get_cap_remain(&mut self) -> Result<u16, Error>;
    fn get_current(&mut self) -> Result<u16, Error>;
    fn get_current_avg(&mut self) -> Result<u16, Error>;
    fn get_flags(&mut self) -> Result<u32, Error>;
    fn get_max_error(&mut self) -> Result<u8, Error>;
    fn get_state_of_charge(&mut self) -> Result<u8, Error>;
    fn get_temp(&mut self) -> Result<u16, Error>;
    fn get_voltage(&mut self) -> Result<u16, Error>;
    fn read_data_flash_class(&mut self, class: u8, data: &mut [u8]) -> Result<(), Error>;
}

pub struct BqXxx<'a> {
    addr: u8,
    i2c: I2c<'a, Blocking>,
}

impl<'a> BqXxx<'a> {
    pub fn new(p: Peripherals, addr: u8) -> Self {
        let this = Self {
            addr: addr,
            i2c: I2c::new_blocking(p.I2C1, p.PB6, p.PB7, Hertz(100_000), Default::default()),
        };
        this
    }

    fn read(&mut self, cmd: Cmd) -> Result<u16, Error> {
        let mut data = [0u8; 2];
        let c = cmd.get();

        match self.i2c.blocking_write_read(self.addr, &[c], &mut data) {
            Ok(()) => trace!("cmd({}): {}", c, (data[1] as u16) << 8 | data[0] as u16),
            Err(Error::Timeout) => {
                error!("Operation timed out");
                return Err(Error::Timeout);
            },
            Err(e) => {
                error!("I2c Error: {:?}", e);
                return Err(e);
            },
        }

        let result = ((data[1] as u16) << 8) | data[0] as u16;
        Ok(result)
    }

    pub fn dev_type(&mut self) -> u16 {
        let mut rx_buffer: [u8; 2] = [0; 2];

        match self.i2c.blocking_write(0x55, &[0, 1, 0]) {
            Ok(()) => debug!("Successful command write"),
            Err(Error::Timeout) => error!("Operation timed out"),
            Err(e) => error!("I2c Error: {:?}", e),
        }

        match self.i2c.blocking_read(self.addr, &mut rx_buffer) {
            Ok(()) => debug!("read(): {:#04x} {:#04x}", rx_buffer[0], rx_buffer[1]),
            Err(Error::Timeout) => error!("Operation timed out"),
            Err(e) => error!("I2c Error: {:?}", e),
        }

        ((rx_buffer[1] as u16) << 8) | rx_buffer[0] as u16
    }
}
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

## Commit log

2024-05-23 Add missing 3D model
    [akkupack-ng.kicad_pcb, ts-1187a-b-a-b.stp]
2024-05-23 Add Blender marks
    [akkupack-ng.kicad_pcb]
2025-05-10 Rearange fabrication data
    [akkupack-ng.kicad_pcb]
2025-05-10 Fix USB
    [akkupack-ng.kicad_pcb, mcu.kicad_sch, serial.kicad_sch]
2025-05-10 Update to KiCAD 9.x
    [akkupack-ng.kicad_pcb, akkupack-ng.kicad_sch, mcu.kicad_sch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]
2025-05-10 Rework Input selection
    [akkupack-ng.kicad_pcb, akkupack-ng.kicad_sch, inputsel.kicad_sch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]
2025-05-10 Rework SWD connector
    [akkupack-ng.kicad_pcb, mcu.kicad_sch]
2025-05-12 Add BAT power disconnector
    [akkupack-ng.kicad_pcb, mcu.kicad_sch]
2025-05-12 Add MCU LEDs
    [akkupack-ng.kicad_pcb, mcu.kicad_sch]
2025-05-15 Enable external I2C programming
    [akkupack-ng.kicad_pcb, inputsel.kicad_sch, mcu.kicad_sch]
2025-05-15 Temp disable print schematic

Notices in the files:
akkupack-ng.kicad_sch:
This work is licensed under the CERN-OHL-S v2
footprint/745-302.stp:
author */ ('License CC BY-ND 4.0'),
